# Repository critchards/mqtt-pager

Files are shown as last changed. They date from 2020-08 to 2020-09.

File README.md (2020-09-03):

# Dad, can you text my friend's dad to see if my friend can play video games online with me?

Sure, **3 or 4 times a day, every day, of the Covid-19 pandemic**, until I probably spent more time texting his dad than my own partner. The Mothers of Invention wasnt just a great band, its also a Necessity!

Then I thought, aren't thinking engines supposed to do this type of drudgery for us? What if there was a device where you could push a button or two, and another device far, far away would light up and make sounds. I bet everyone and their mother would want one. You could probably sell these things by the bushel. But they would need a catchy name. Sell... Sell... sell what? Sell.. why? Sell for... not enterrupting. Sell for not enterrupting. Too long, shorten it to Sell FO-NE... perfect!

All kidding aside, I thought wouldn't it be neat if my son has a button he could push that would alert his friends he wanted to play. And if they wanted to play too, they could hit a button on their side that let my son know they wanted to play also. I imagined it sending out a call like OCTONAUTS TO THE LAUNCH BAY, or PAW PATROL TO THE LOOKOUT. Hell even my buddies would probably want one...   
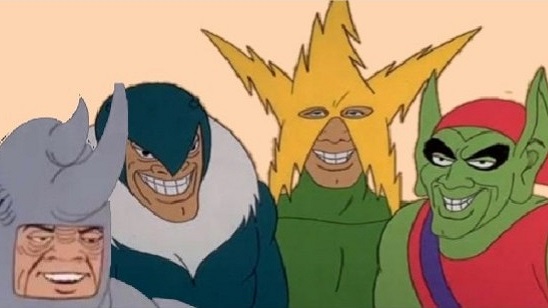
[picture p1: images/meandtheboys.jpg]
meandtheboys
 <br>

I also had watched a couple great online workshops about IoT using these cheap little developer boards and thought it would be a great opportunity to stretch my knowledge. **A big thankyou to jimbobbennet and wduraes for their workshops on IoT and arduino.**  
1. https://github.com/wduraes/Workshops/tree/master/IoT%20101%20for%20Makers - Start here for a great explanation of how mqtt works and free to use Adafruit.io
2. https://github.com/jimbobbennett/BusyLight - Here for more sophisticated Azure IoT Central approach

# Define the Problem
  So the use case is: Device sits minding its own business until someone wants to play. They push a button, sending a request to play. All connected devices make some kind of an alert for a short period of time. If anyone wants to play,  they push a button on their device and all other devices play a different type of alert to let every know there is a response. You won't know who answered your call until you fire up your game, but you know someone will be there to join. 
  I want this device to be as cheap as possible (since Im going to be giving them out to my son's friends families), be plug and play, and be interesting enough to the target demographic that they don't lose/destroy it in the first few days.
<br>*image for state diagram*

## How are we going to solve this?
Through a luckly alignment of the stars I had learned almost everything I needed in the last few months to almost know what I was doing. And even more lucky, this particular project was not dangerous enough that my little bit of knowledge was going to get anyone hurt. Basically, using the ESP8266 NodeMCU Dev board, and Adafruit.io I had a platform for MQTT. Add your basic buttons, LEDs and buzzers and that is all we need. Package it all on a prototyping board for the high tech look and that should be enough to keep it interesting. (And accomodate my numerous mistakes. :) )
1. [Hardware - ESP8266/ESP32](/steps/hardware.md)
2. [Software - Arduino](/steps/software.md)

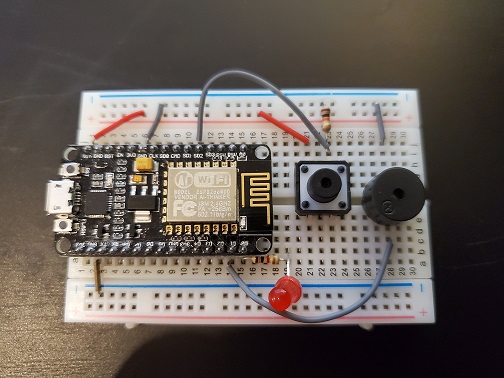
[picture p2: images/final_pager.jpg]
Shazam!

# next Steps
1. device has been ringing the system even when no button push, figure out why
3. add button interrupt
2. figure out public feeds to see if multiple people can use devices without having to pre-populate

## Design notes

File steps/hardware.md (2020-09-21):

## Materials List ##
Its all Amazon links, becuase thats easiest for me to find. I bought most of this stuff from [Adafruit](https://www.adafruit.com/) though and I suggest you go there if you have the option.
1. 2x [NodeMCU ESP8266 EDP 12-E Development board](https://www.amazon.com/HiLetgo-Internet-Development-Wireless-Micropython/dp/B010O1G1ES) These boards should be gettable for less than $5 each. You can also use [DOIT ESP32 DevBoard](https://www.amazon.ca/dp/B07HG5XHLB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) if you have them. They are more expensive but have BLE for other projects down the line. A couple of changes are noted in the .ino file though if you use the ESP32.
2. 2x [Half sized breadboard](https://www.amazon.com/Breadboard-Solderless-Prototype-PCB-Board/dp/B077DN2PS1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)
3. 2x [12mm tactile button](https://www.amazon.com/TWTADE-Momentary-Tactile-Button-Switch/dp/B07CG6HVY9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)
4. 2x [5V 2 terminal buzzer](https://www.amazon.com/Cylewet-Terminals-Electronic-Electromagnetic-Impedance/dp/B01NCOXB2Q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) You can go with bigger/louder if you want. These ones are not going to be audible from the other side of the house but you should be able to hear them in the same room even with background noise.
5. 2x [5mm LED](https://www.amazon.com/eBoot-Pieces-Emitting-Diodes-Assorted/dp/B06XPV4CSH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) Whichever color you want.
6. 2x [300Ohm resistor](https://www.amazon.com/Elegoo-Values-Resistor-Assortment-Compliant/dp/B072BL2VX1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) just buy a kit.
7. 2x 4.7kOhm resistor - from the same kit. Strictly speaking this is not necessary since you can use the built in pulldown function of the board but this is how I was taught...
8. And some jumper wires.

Wire it up as so
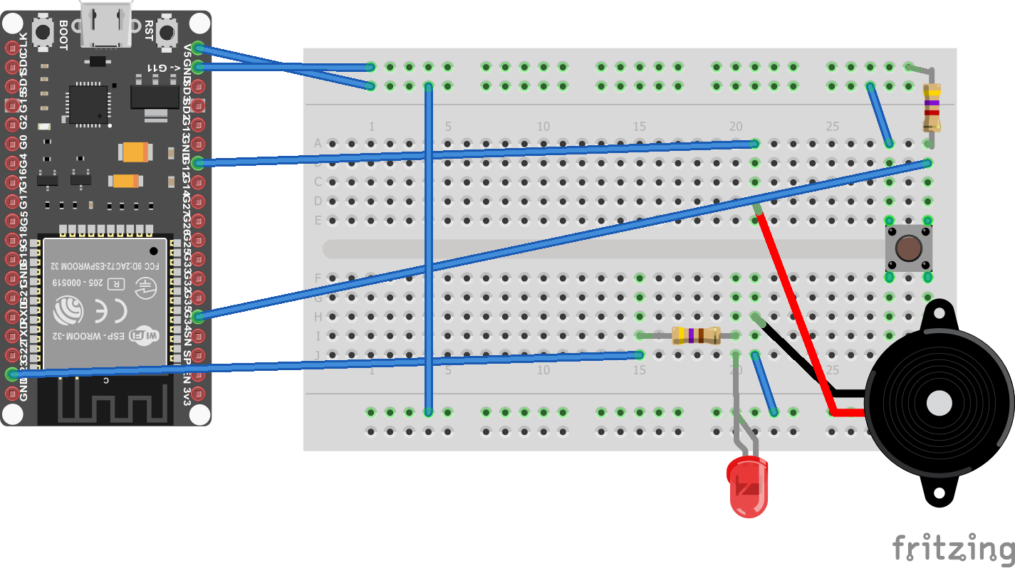
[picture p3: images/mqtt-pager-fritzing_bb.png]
Fritz


Note this is with the DOIT ESP32 Board which doesnt exactly fit on the half sized breadboard.

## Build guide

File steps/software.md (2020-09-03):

# Software Setup #
The software part of this project includes the arduino code, and how to get the arduino code onto the device. [wduraes tutorial](https://github.com/wduraes/Workshops/tree/master/IoT%20101%20for%20Makers) does a great explanation on how to setup Arduino to work with the ESP8266 board inlcuding necessary libraries for mqtt.

## Arduino Setup ##
Add additional board definition files
Under Files/Preferences copy this string into the Additional Board Manager URLs field. (Note you can have multiple by seperating them with a ,)
### For ESP8266 ###
`http://arduino.esp8266.com/stable/package_esp8266com_index.json`
### For ESP32 ###
`https://dl.espressif.com/dl/package_esp32_index.json`

Restart Arduino to update the boards.
Add necessary libraries.
Under Tools/Library Manager, use the search bar and add the following libraries
- Adafruit MQTT by Adafruit

You will also have to manually add the [Tone32 library from Ibernstone](https://github.com/lbernstone/Tone32) if you are using the ESP32. Copy the repo into your Arduino/Libraries folder.

## Adafruit.io Setup ##
Get yourself an account, its free.
Create a feed. Note your username and AIO key.

## Code Changes ##
There are commented #include statements depending on if you are using the ESP8266 or ESP32
You need to add your SSID, wifi password, Adafruit.io user name, adafruit.io key and the name of your feed.

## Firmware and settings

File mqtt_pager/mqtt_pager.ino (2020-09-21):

  //some parts of this have been copied from adafruit, and some from wduraes. You can tell from the {convention}
  
  #include <ESP8266WiFi.h>					//use this one if you have an ESP8266
  //#include <Wifi.h>						    //use this one if you have an ESP32
  //#include <Tone32.h>						  //Tone is not implemented on the ESP32, need to manually install this library
  #include "Adafruit_MQTT.h"
  #include "Adafruit_MQTT_Client.h"

  #define WLAN_SSID       "THE WIFI NAME GOES HERE"					//for whichever house this device is going to live at
  #define WLAN_PASS       "THE WIFI PASSWORD GOES HERE"				//for whichever house this device is going to live at
  #define AIO_SERVER      "io.adafruit.com"
  #define AIO_USERNAME    "YOUR ADAFRUIT USER NAME GOES HERE"
  #define AIO_KEY         "COPY YOUR ADAFRUIT.IO KEY HERE"
  #define AIO_SERVERPORT  1883
  #define BUZZER_CHANNEL 0                                  //needed for Tone32 implementation
                     
  WiFiClient client;
  //#define AIO_SERVERPORT  8883     // use 8883 for SSL
  //WiFiClientSecure client;  // use WiFiFlientSecure for SSL

  Adafruit_MQTT_Client mqtt(&client, AIO_SERVER, AIO_SERVERPORT, AIO_USERNAME, AIO_KEY);
  Adafruit_MQTT_Publish request = Adafruit_MQTT_Publish(&mqtt, AIO_USERNAME "/feeds/YOUR FEED NAME");			//change YOUR FEED NAME
  Adafruit_MQTT_Subscribe response = Adafruit_MQTT_Subscribe(&mqtt, AIO_USERNAME "/feeds/YOUR FEED NAME");		//change YOUR FEED NAME

  void MQTT_connect();

  const int BUTTONPIN = 9;    //set button output pin
  const int LEDPIN = 16;       //set status LED To pin number
  const int TONEPIN = 5;     //set buzzer to pin number, for DOIT ESP32 boards use 12
  const int MAXRINGS = 7;    //max number of rings  

  int ledState = LOW;         //for LED SM
  int toneState = LOW;        //for tone SM
  int lastButtonState = 0;  //for button edge detect
  int buttonState = 0;		//for current button state
  int numRings = 0;     //count number of times I have rung

  bool Ringing = false;		//am i ringing or not

  unsigned long currentTime = 0;      //SM global timer
  unsigned long prePing = 0;          //SM timer for ping
  unsigned long preSubscribe = 0;     //SM timer for subscription check
  unsigned long lastRing = 0;         //SM for LED and tone on during ring
  unsigned long lastTone = 0;         //SM timer for tone
  unsigned long lastDebounceTime = 0; //SM timer for button debounce
     
  void setup() 
  {       
    Serial.begin(115200);
    pinMode(LEDPIN, OUTPUT);
    pinMode(BUTTONPIN, INPUT);
  
    // Connect to WiFi access point.
    Serial.println(); Serial.println();
    Serial.print("Connecting to ");
    Serial.println(WLAN_SSID);
  
    WiFi.begin(WLAN_SSID, WLAN_PASS);
    while (WiFi.status() != WL_CONNECTED) 
    {
      digitalWrite(LED_BUILTIN, LOW);   //turn onboard LED ON
      delay(500);
      digitalWrite(LED_BUILTIN, HIGH);    //turn onboard LED OFF
      Serial.print(".");
    }
    Serial.println();
    Serial.println("WiFi connected");
    Serial.println("IP address: "); Serial.println(WiFi.localIP());
    
    // Setup MQTT subscriptions for all feeds.
    mqtt.subscribe(&response);

    digitalWrite(LEDPIN, ledState);
  }
     
  void loop() 
  {
    currentTime = millis();
    MQTT_connect();
   
    Adafruit_MQTT_Subscribe *subscription;
    if((currentTime - preSubscribe) > 5000)             //check for subscriptions only every few seconds, adafruit.io doesnt like being pinged continuously
    {
      //Serial.println("checking for subscriptions");
      preSubscribe = currentTime;
      while ((subscription = mqtt.readSubscription(500))) 		//keep subscription window open for a short period so that button pushes dont get lost. OR, fix buttons to be interrupts
      {
        if (subscription == &response)
        {
          Serial.print(F("Subscription Got: "));
          Serial.println((char *)response.lastread);
        }
        if (strcmp((char *)response.lastread, "WAITING") == 0) 
        {
          //if you see waiting, dont do anything
          Ringing = false;
        } 
        if (strcmp((char *)response.lastread, "RINGING") == 0) 
        {
          //if someone sent a request, ring the device
          Ringing = true;
        }
        if (strcmp((char *)response.lastread, "CONFIRM") == 0) 
        {
          //if someone answered the ring, play a merry tune, then go back to waiting
		  celebrate();
          Ringing = false;
        }       
      }
    }           

    int reading = digitalRead(BUTTONPIN);				//check the status of the pushbutton
    if(reading != lastButtonState)						//only do something if the button has changed. May need to debounce?
    {
      if(reading == 1)      //if button is high, set to high
      {
        buttonState = 1;
      }
    }
    else                    //if the button state hasnt changed, set button to low. This handles extra long presses.
    {
      buttonState = 0;
    }
    lastButtonState = reading;
    
    if(buttonState == 1)	//if the button is truly being pressed, after removing long presses
    {
      if(!Ringing)			//if the device is not already ringing then this must be the first device sending a request
      {
        if(request.publish("RINGING"))		//publish ringing so that all devices know they should be ringing
        {
          numRings = 0;						//keep track of number of rings so it doesnt go on for ever
          Ringing = true;				
          Serial.print("sending request to play as: ");
          Serial.print("RINGING");
          Serial.println("...");
        }  
      }
      else if(Ringing)						//if the device is alraedy ringing then this must be an answer
      {
          request.publish("CONFIRM");		//publish confirm so all devices know someone answered
          Ringing = false;					//stop ringing
      }
      buttonState = 0;						//set button back to off, again in case of extra long presses
    }

    if(Ringing)               //when ringing, flash lights and play tone, all on different periods, NON BLOCKING
    {
      if((toneState == HIGH) && (currentTime - lastTone > 100))		//SM for shutting buzzer off
      {
        toneState = LOW;
        lastTone = currentTime;
        noTone(TONEPIN);                                          //if using ESP8266
        //noTone(TONEPIN, BUZZER_CHANNEL);                        //if using ESP32
      }
      if((toneState == LOW) && (currentTime - lastTone > 500))		//SM for turning buzzer on
      {
        toneState = HIGH;
        lastTone = currentTime;
        tone(TONEPIN, 1000);                                      //ESP8266
        //tone(TONEPIN, 1000, 0, BUZZER_CHANNEL);                 //ESP32
      }
      if((ledState == LOW) && (currentTime - lastRing > 1000))		//SM for turning LED off
      {
        ledState = HIGH;
        lastRing = currentTime;
        digitalWrite(LEDPIN, ledState);
      }
      if((ledState == HIGH) && (currentTime - lastRing > 1000))		//SM for turning LED on
      {
        ledState = LOW;
        lastRing = currentTime;
        digitalWrite(LEDPIN, ledState);
        numRings++;													//number of rings is defined as number of times LED turns on
      }
    }

    if(numRings > MAXRINGS)             //if it has been ringing for too long, stop and reset
    {
      if(request.publish("WAITING"))     //publish WAITING so that system knows no request in progress
      {
        Serial.println("max rings, send waiting");
        digitalWrite(LEDPIN, LOW);
        noTone(TONEPIN);                        //ESP8266
        //noTone(TONEPIN, BUZZER_CHANNEL);        //ESP32           
        Ringing = false;                
        numRings = 0;
      }
    }
     
    if((currentTime - prePing) > 290000)        //ping the broker every keep alive duration, configurable in settings     
    {
        Serial.println("ping mqtt");
        prePing = currentTime;
        if(! mqtt.ping())
        {
          Serial.println("ping not work, kill mqtt");
          mqtt.disconnect();
        }
    }
  }  

  // Function to connect and reconnect as necessary to the MQTT server.
  // Should be called in the loop function and it will take care if connecting.
  // copied directly from wduraes IoT_101_Online.ino
  void MQTT_connect() {
    
    int8_t ret;
    if (mqtt.connected()) {      // Stop if already connected.
      return;
      }
    Serial.print("Connecting to MQTT... ");
    uint8_t retries = 3;
    while ((ret = mqtt.connect()) != 0) { // connect will return 0 for connected
         Serial.println(mqtt.connectErrorString(ret));
         Serial.println("Retrying MQTT connection in 5 seconds...");
         mqtt.disconnect();
         delay(5000);  // wait 5 seconds
         retries--;
         if (retries == 0) {
           // basically die and wait for WDT to reset me
           while (1);
         }
    }
    Serial.println("MQTT Connected!");
  }

  void celebrate()
  //flash lights and play merry tone to indicate a request has been answered and play will commence.
  //BLOCKING
  {
    for(int j = 0; j<3; j++)
    {
      for(int i = 0; i<3; i++)
      {
        digitalWrite(LEDPIN, HIGH);
        tone(TONEPIN, 500);
        //tone(TONEPIN, 500, 0, BUZZER_CHANNEL);    //ESP32
        delay(100);
        tone(TONEPIN, 650);
        //tone(TONEPIN, 650, 0, BUZZER_CHANNEL);    //ESP32
        delay(100);
        tone(TONEPIN, 1000);
        //tone(TONEPIN, 1000, 0, BUZZER_CHANNEL);    //ESP32
        delay(100);
        noTone(TONEPIN);
        //noTone(TONEPIN, BUZZER_CHANNEL);           //ESP32
        digitalWrite(LEDPIN, LOW);
        delay(300);
      }
      delay(600);
    }
    request.publish("WAITING");
    Ringing = false;
  }

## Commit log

2020-09-01 ESP32 fritzing
    Create fritzing of ESP32 variant
    [mqtt-pager-fritzing.fzz]
2020-09-03 Update mqtt_pager.ino
    Add includes for ESP32
2020-09-04 folders
    add root folder for arduino
2020-09-04 Add ESP32 comments
    -Tone32 requires different parameters
2020-09-21 update fritz schematic
    update to make esp32 layout more clear
    [mqtt-pager-fritzing.fzz]
